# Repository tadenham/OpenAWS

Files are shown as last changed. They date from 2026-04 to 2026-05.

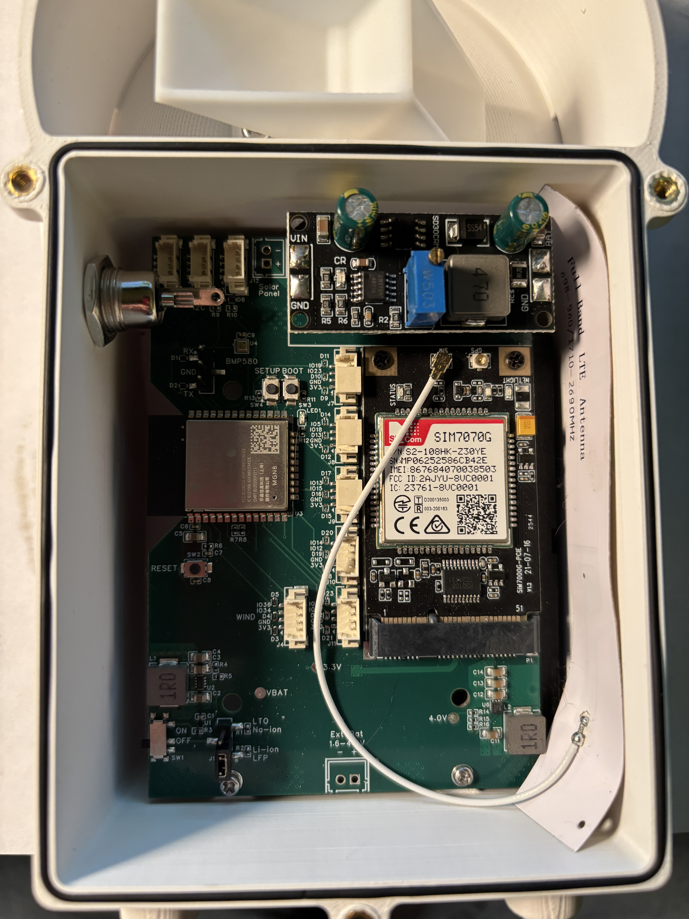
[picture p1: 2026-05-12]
photos/MainPCB.JPG

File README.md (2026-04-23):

OpenAWS is an ESP32-based automated remote weather station. The station transmits via cellular or satellite network.

Currently, the following modules are supported:
 SIMCom SIM7070G (GSM/LTE-M/NB-IoT),
  SIMCom A7670G (GSM/LTE Cat-1),
  and Murata Type 1SC-NTN (NB-NTN geostationary satellite)
 
OpenAWS supports the following sensors:
  temperature/humidity (Sensirion SHT4x or SHT3x),
  precipitation (hall switch),
  barometric pressure (Bosch BMP580),
  wind speed (hall switch),
  and wind direction (AMS AS5600)

The station transmits to the OpenAWS server over UDP and receives a Unix timestamp in response which is used to set the ESP32 clock. This eliminates dependence on unreliable NITZ or NTP updates.
If a response is not received from the server, the data is stored locally and retransmitted at a later time. This ensures guaranteed delivery.

Major station settings are configured in the settings.h file. Otherwise, the station is configured at installation via Bluetooth.

Please visit OpenAWS.org to view stations and further documentation.

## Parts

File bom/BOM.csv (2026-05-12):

Item | Description | Quantity | Material | Notes
1 | Housing, AWS | 1 | ASA | 3D printed
2 | Insert, heat set, M2-0.4 | 3 | Brass | Main PCB/housing
3 | PCB, main | 1 | Various
4 | Holder, battery, 18650, 2-cell | 2 | Various | Soldered to item 3
5 | Battery, lithium-titanate, 18650, 1500 mAh | 4 | Various
6 | Screw, M2-0.4 x 5 mm lg | 3 | Stainless steel | Main PCB/housing
7 | PCB, charger, CN3795 | 1 | Various
8 | Header, male, 2.54 mm pitch, 2P | 2 | Various | Soldered to item 7
9 | Header, female, 2.54 mm pitch, 2P | 2 | Various | Soldered to item 3
10 | Cap, jumper, 2.54 mm pitch, 2P | 1 | Various | Battery voltage selection
11 | PCB, module, SIM7070G | 1 | Various
12 | Standoff, M2-0.4 x 1.5 mm | 2 | Brass | Soldered to item 3
13 | Screw, M2-0.4 x 4 mm | 2 | Stainless steel | Module/Main PCB
14 | Antenna, LTE | 1 | Various | 698-960 MHz, 1710-2690 MHz
15 | Card, SIM, Nano | 1 | Various
16 | Socket, DC, 5.5 mm x 2.1 mm, w/nut | 1 | Various | Solar panel connector
17 | Cable, JST-XH, 2P, 100 mm lg, end 1 female connector, end 2 pigtail, w/male connector | 1 | Various | Solar panel connector
18 | O-ring, 9 mm x 1.2 mm | 1 | Buna-N | Solar panel connector
19 | Plug, snap-in, 8 mm | 1 | Rubber | Use when item 20 is not installed
20 | Receptacle, M8, 4P, rear panel mount, female, w/o-ring and nut | 1 | Various | Required for anemometer
21 | Cable, JST-GH, 4P, 100 mm lg, end 1 female connector, end 2 pigtail | 1 | Various | Required for anemometer
22 | Cable, JST-GH, 4P, 100 mm lg, end 1 female connector, end 2 female connector | 1 | Various | Temperature/humidity sensor
23 | Cover, housing | 1 | ASA | 3D printed
24 | Insert, heat set, M3-0.5 | 4 | Brass | Cover/housing
25 | O-ring, 1.5 mm x 375 mm lg | 1 | Buna-N | Cover/housing
26 | Screw, M3-0.5 x 6 mm | 4 | Stainless steel | Cover/housing
27 | Level, bull's eye, 15 mm x 8 mm | 1 | Various
28 | Insert, heat set, M4-0.7 | 2 | Brass | Radiation shield/housing
29 | Plug, housing | 1 | ASA | 3D printed
30 | Housing, PCB, SHT45 | 1 | 9600 resin | Tap M3-0.5 thru
31 | Insert, PCB, SHT45 | 1 | 9600 resin
32 | Screw, set, nylon-tipped, M3-0.5 x 6 mm | 1 | Various | PCB housing/insert/PCB
33 | PCB, SHT45 | 1 | Various
34 | Plate, shield, radiation, middle | 5 | ASA | 3D printed
35 | Plate, shield, radiation, bottom | 1 | ASA | 3D printed
36 | Screw, socket head, M4-0.7 x 85 mm | 2 | Stainless steel | Radiation shield/housing
37 | Bucket, tipping | 1 | 9600 resin
38 | Pin, dowel, 1/16" x 1-1/4" lg | 1 | Stainless steel | Tipping bucket
39 | Magnet, 1/8" dia. x 1/16" lg, magnetized through thickness | 1 | Neodymium | Tipping bucket
40 | Screen, funnel | 1 | Stainless steel
41 | Mount, panel, solar, adjustable | 1 | ASA | 3D printed
42 | Insert, heat set, M4-0.7 | 2 | Brass | Solar panel mount/housing
43 | Screw, M4-0.7 x 10 mm | 2 | Stainless steel | Solar panel mount/housing
44 | Insert, heat set, M3-0.5 | 2 | Brass | Solar panel/solar panel mount
45 | Panel, solar, 12 V, 4 W | 1 | Various | 2x drill 3mm thru
46 | Screw, M3-0.5 x 6 mm | 2 | Stainless steel | Solar panel/solar panel mount
47 | Washer, flat, M3 | 2 | Stainless steel | Solar panel/solar panel mount
48 | Clamp | 1 | ASA | 3D printed
49 | Insert, heat set, M6-1.0 | 4 | Brass | Clamp/housing
50 | Screw, socket head, M6-1.0 x 35 mm | 4 | Stainless steel | Clamp/housing

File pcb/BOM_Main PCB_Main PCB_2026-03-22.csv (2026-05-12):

No. | Quantity | Comment | Designator | Footprint | Value | Manufacturer Part | Manufacturer | Supplier Part | Supplier
1 | 2 | 2X 18650 | BT1,BT2 | BAT-SMD_BH-18650-B1BA007 |  | BH-18650-B1BA007 | MYOUNG(??) | C6937126 | LCSC
2 | 7 | 100nF | C1,C6,C7,C8,C9,C10,C15 | C0402 | 100nF | CL05B104KO5NNNC | SAMSUNG(??) | C1525 | LCSC
3 | 8 | 22uF | C2,C3,C4,C5,C11,C12,C13,C14 | C0805 | 22uF | CL21A226MAQNNNE | SAMSUNG(??) | C45783 | LCSC
4 | 1 | SMN-303 | CARD1 | SIM-SMD_SMN-303 |  | SMN-303 | XUNPU(??) | C266888 | LCSC
5 | 13 | TPD1E1B04DPYR | D1,D2,D3,D4,D5,D6,D7,D8,D24,D25,D26,D27,D28 | X1SON-2_L1.0-W0.6-P0.65-BI-1 |  | TPD1E1B04DPYR | TI(????) | C779408 | LCSC
6 | 2 | HX PZ2.54-1x3P TP-YQ | J1,J2 | HDR-SMD_3P-P2.54-V-M_HX-PZ2.54-1X3P-TP-YQ |  | HX PZ2.54-1x3P TP-YQ | hanxia(??) | C41417360 | LCSC
7 | 9 | ZX-MX1.25-4PLT | J3,J4,J5,J6,J7,J8,J9,J10,J11 | CONN-SMD_4P-P1.25_MEGASTAR_ZX-MX1.25-4PLT |  | ZX-MX1.25-4PLT | Megastar(??) | C7430475 | LCSC
8 | 1 | ZX-XH2.54-2PZZ | J12 | CONN-TH_2P-P2.50_HX25003-2A |  | ZX-XH2.54-2PZZ | Megastar(??) | C7429632 | LCSC
9 | 2 | PM254V-11-02-H85 | J13,J14 | HDR-TH_2P-P2.54-V-F |  | PM254V-11-02-H85 | XFCN(??) | C541849 | LCSC
10 | 2 | 1uH | L1,L2 | IND-SMD_L7.0-W6.6 | 1uH | FXL0630-1R0-M | cjiang(????) | C167216 | LCSC
11 | 1 | KT-0603R | LED1 | LED0603-RD |  | KT-0603R | KENTO | C2286 | LCSC
12 | 1 | PCIE-52P52H | P1 | CONN-SMD_PCIE-52P52H |  | PCIE-52P52H | XUNPU(??) | C266899 | LCSC
13 | 1 | 200k? | R1 | R0402 | 200k? | 0402WGF2003TCE | UNI-ROYAL(??) | C25764 | LCSC
14 | 1 | 576k? | R2 | R0402 | 576k? | 0402WGF5763TCE | UNI-ROYAL(??) | C27012 | LCSC
15 | 6 | 511k? | R3,R4,R7,R8,R14,R16 | R0402 | 511k? | 0402WGF5113TCE | UNI-ROYAL(??) | C64042 | LCSC
16 | 2 | 91k? | R5,R15 | R0402 | 91k? | 0402WGF9102TCE | UNI-ROYAL(??) | C4147 | LCSC
17 | 2 | 10k? | R6,R13 | R0402 | 10k? | 0402WGF1002TCE | UNI-ROYAL(??) | C25744 | LCSC
18 | 3 | 4.7k? | R9,R10,R11 | R0402 | 4.7k? | 0402WGF4701TCE | UNI-ROYAL(??) | C25900 | LCSC
19 | 1 | 1k? | R12 | R0402 | 1k? | 0402WGF1001TCE | UNI-ROYAL(??) | C11702 | LCSC
20 | 4 | 22? | R17,R18,R19,R20 | R0402 | 22? | 0402WGF220JTCE | UNI-ROYAL(??) | C25092 | LCSC
21 | 1 | SK-3296S-01-L1 | SW1 | SW-SMD_3P-P1.50_L2.7-W6.6 |  | SK-3296S-01-L1 | XKB Connection(????) | C319020 | LCSC
22 | 3 | TS-1088-AR02016 | SW2,SW3,SW4 | SW-SMD_L3.9-W3.0-P4.45 |  | TS-1088-AR02016 | XUNPU(??) | C720477 | LCSC
23 | 3 | Test-Point | TP1,TP2,TP3 | Test-Point-0.5mm
24 | 1 | TLV4041R1YKAR | U1 | DSBGA-4_L0.7-W0.7-R2-C2-P0.35-TL |  | TLV4041R1YKAR | TI(????) | C2871475 | LCSC
25 | 1 | TPS631000DRLR | U2 | SOT-583-8_L2.1-W1.2-P0.50-LS1.6-BL |  | TPS631000DRLR | TI(????) | C5219190 | LCSC
26 | 1 | ESP32-WROOM-32E-N8 | U3 | WIFI-SMD_ESP32-WROOM-32E | 2.4GHz | ESP32-WROOM-32E-N8 | ESPRESSIF(??) | C701342 | LCSC
27 | 1 | BMP580 | U4 | LGA-10_L2.0-W2.0-P0.50-TL_BMP580 |  | BMP580 | Bosch(??) | C22391138 | LCSC
28 | 1 | CC6201ST | U5 | SOT-23-3_L2.9-W1.3-P1.90-LS2.4-BR |  | CC6201ST | CrossChip(????) | C285995 | LCSC
29 | 1 | TPS61022RWUR | U6 | VQFN-7_L2.0-W2.0-P0.55-TL_RWU |  | TPS61022RWUR | TI(????) | C915088 | LCSC

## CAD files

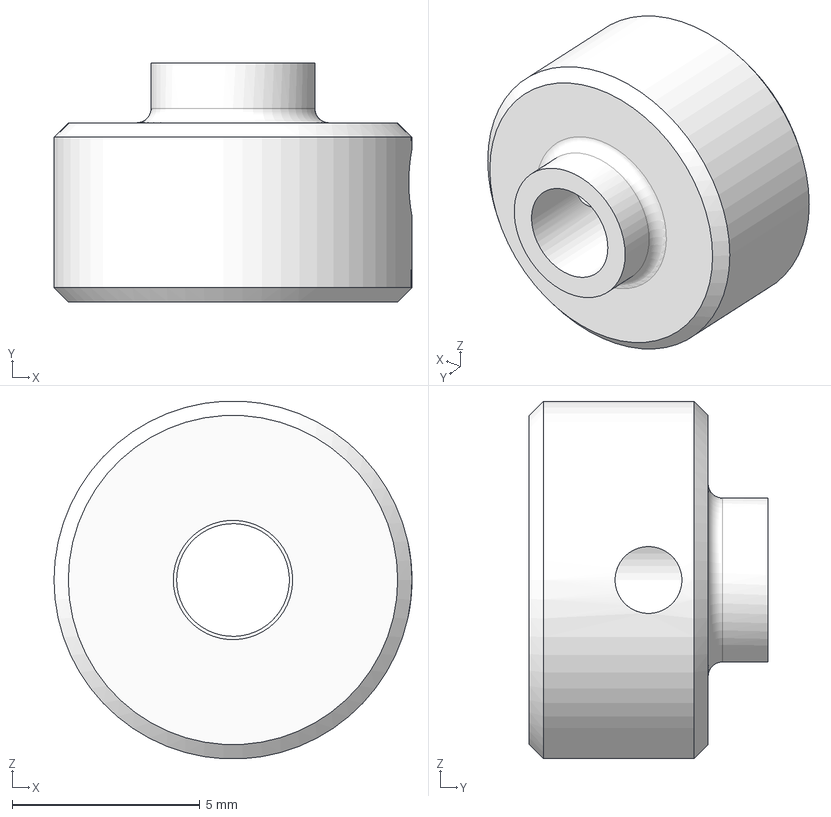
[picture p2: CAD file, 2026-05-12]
cad/WindDirectionMagnetHub.stp
9.52 x 6.35 x 9.51 mm

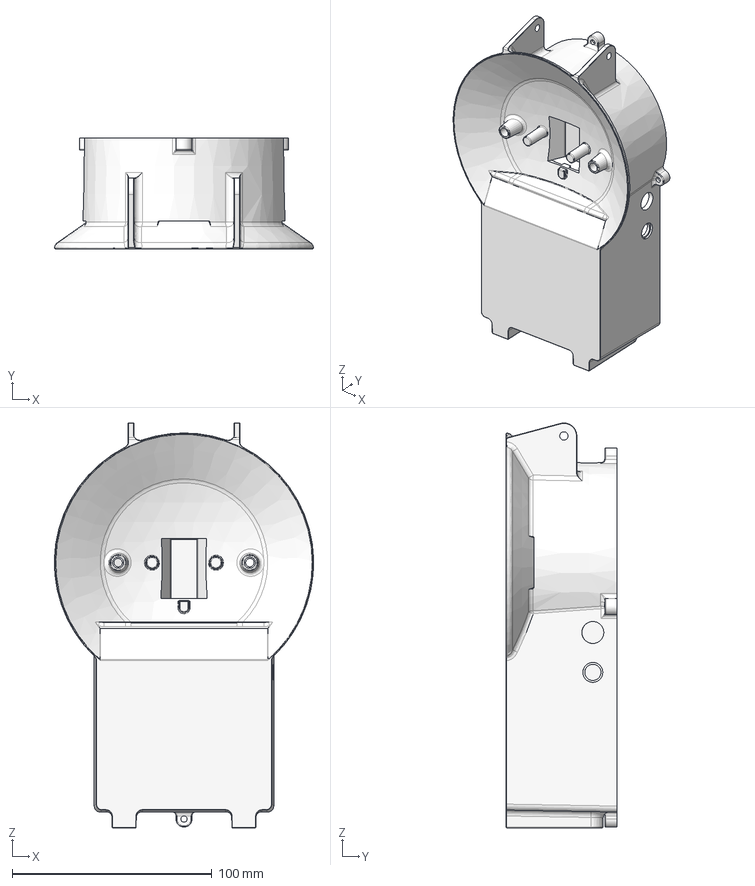
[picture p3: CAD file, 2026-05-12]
cad/AWSHousing.stp
129.9 x 55.4 x 203.0 mm

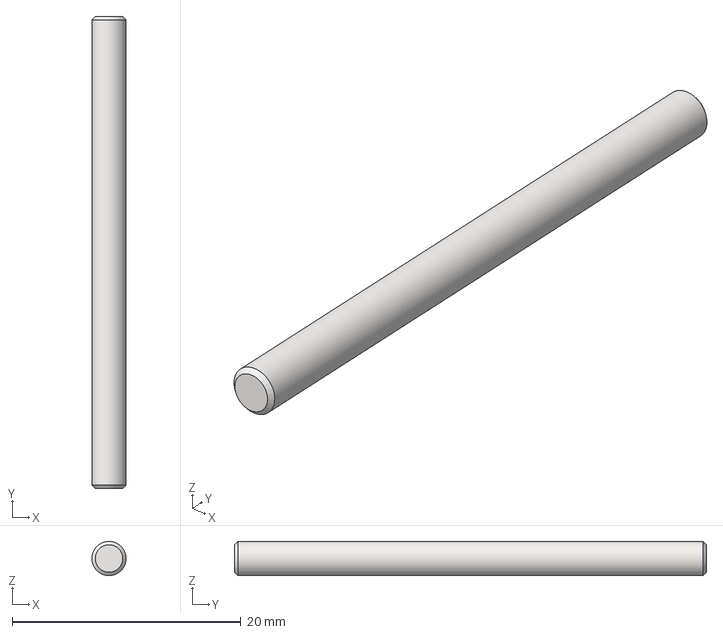
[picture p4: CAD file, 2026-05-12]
cad/WindSpeedShaft.stp
3.00 x 41.3 x 3.00 mm

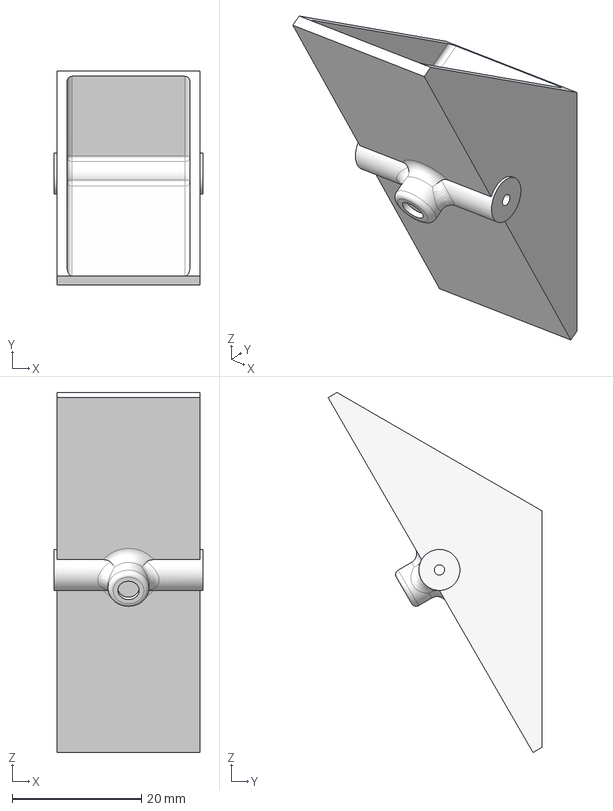
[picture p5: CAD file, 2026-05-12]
cad/RainGaugeBucket.stp
23.0 x 33.1 x 55.8 mm

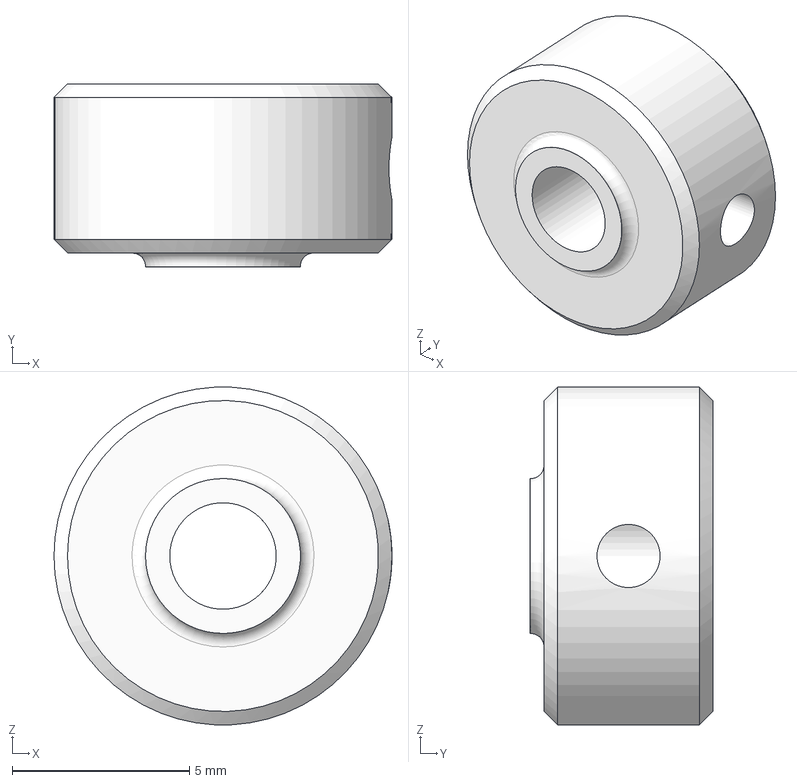
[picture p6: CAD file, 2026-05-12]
cad/ShaftCollar.stp
9.52 x 5.16 x 9.51 mm

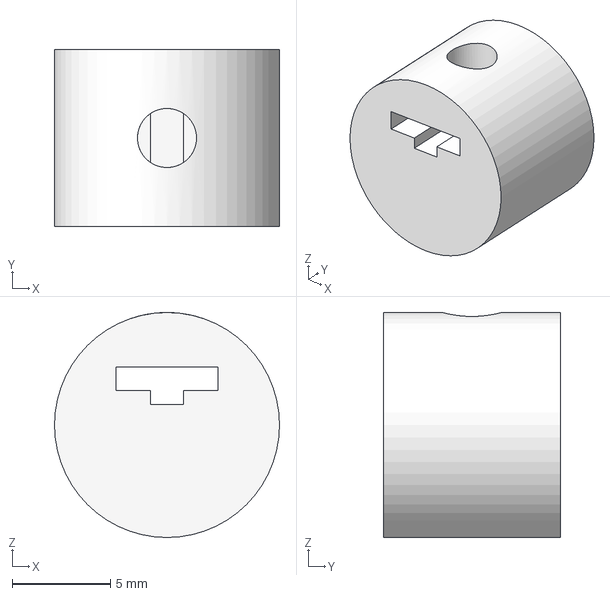
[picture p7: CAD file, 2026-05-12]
cad/TemperatureHumidityPCBInsert.stp
11.4 x 9.00 x 11.4 mm

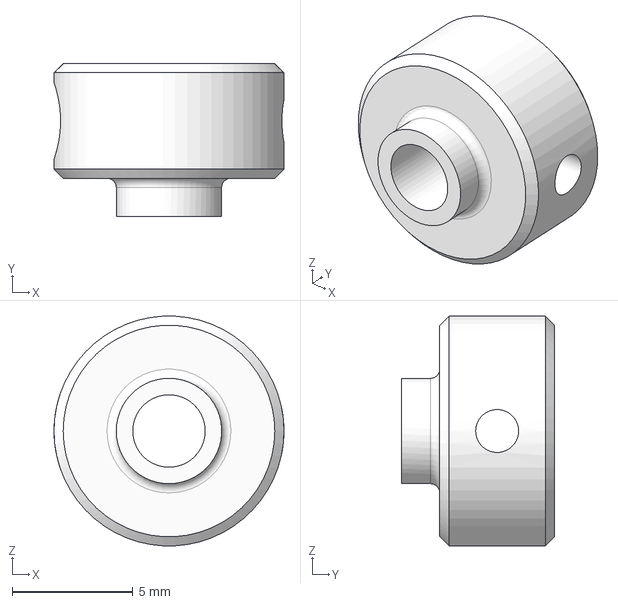
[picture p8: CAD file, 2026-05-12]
cad/WindSpeedMagnetHub.stp
9.52 x 6.35 x 9.51 mm

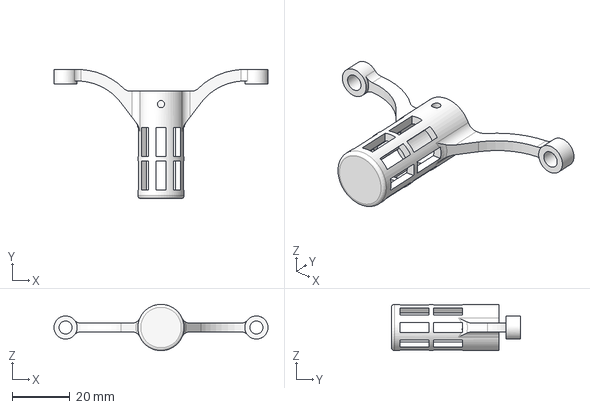
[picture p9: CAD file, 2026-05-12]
cad/TemperatureHumidityPCBHousing.stp
74.0 x 44.7 x 16.0 mm

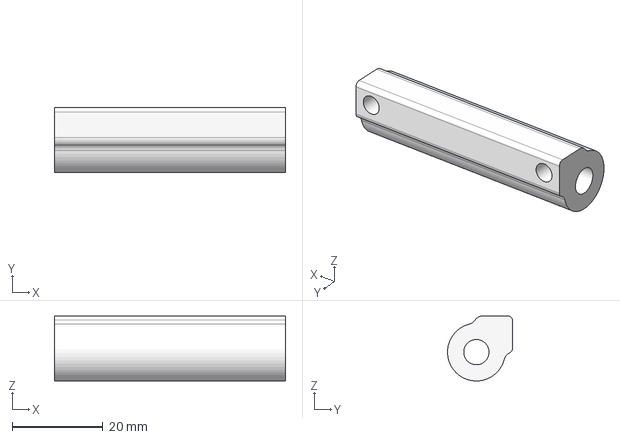
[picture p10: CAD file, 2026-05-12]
cad/SolarPanelMount_Adj.stp
50.8 x 14.3 x 14.3 mm

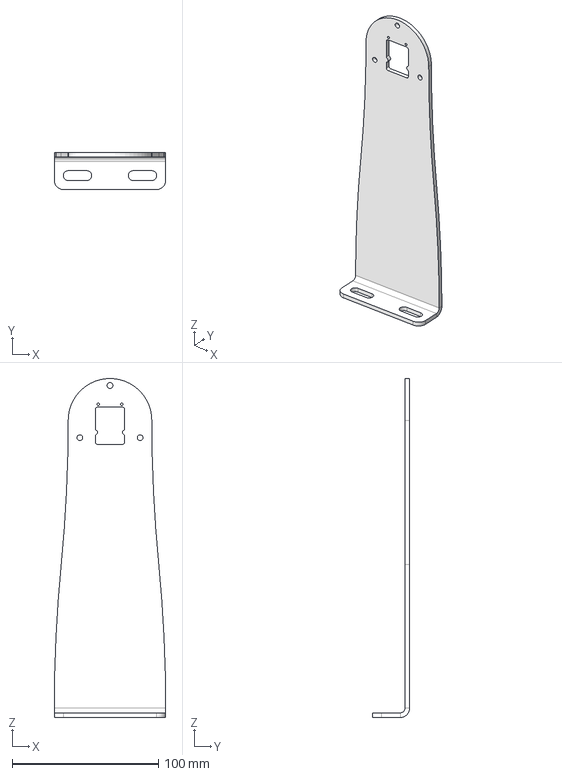
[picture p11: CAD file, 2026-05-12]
cad/AnemometerBracket.stp
76.2 x 25.4 x 231.8 mm

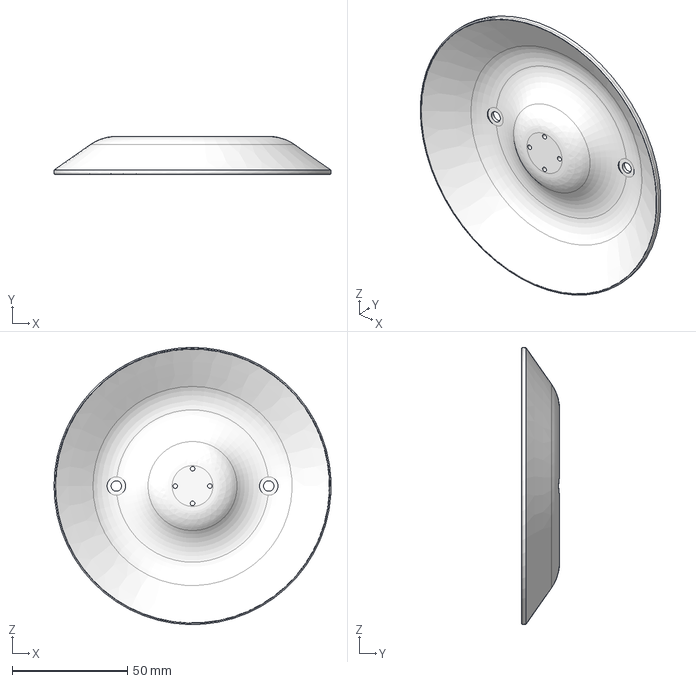
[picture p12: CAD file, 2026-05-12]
cad/RadiationShieldBottomPlate.stp
120.0 x 16.6 x 120.0 mm

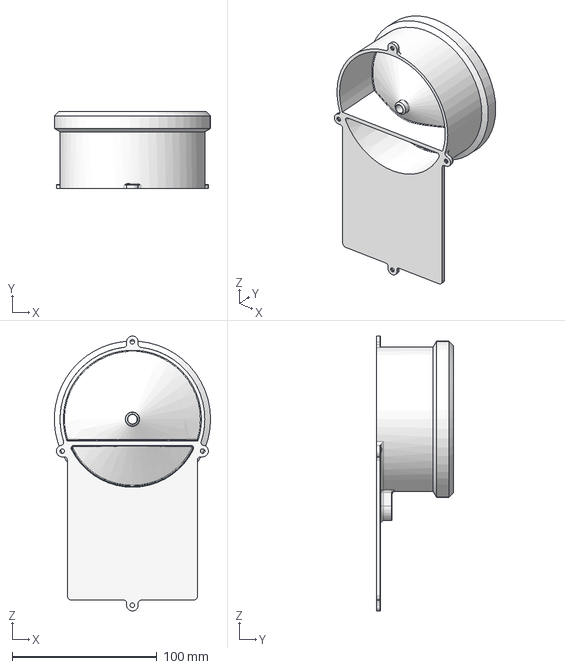
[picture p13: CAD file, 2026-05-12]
cad/AWSHousingCover.stp
107.9 x 53.5 x 190.0 mm

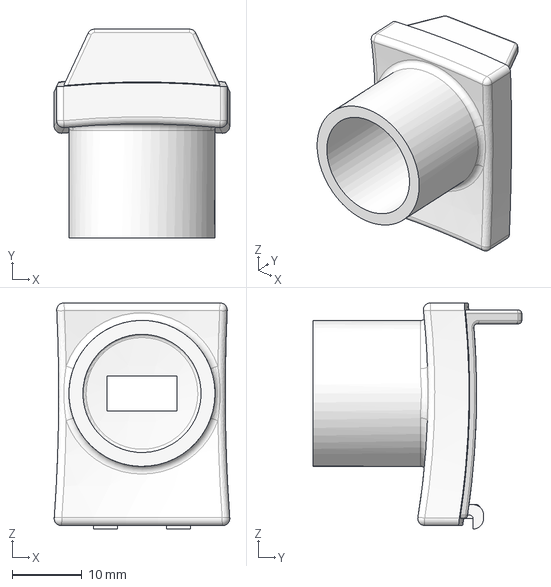
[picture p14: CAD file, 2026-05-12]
cad/AWSHousingPlug.stp
25.3 x 30.0 x 32.5 mm

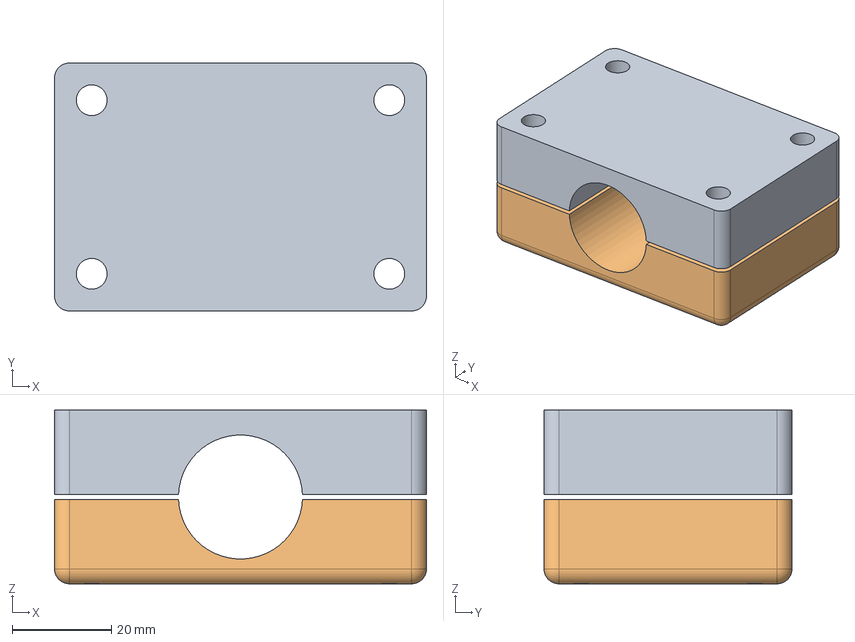
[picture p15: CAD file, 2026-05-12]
cad/Clamp.stp
75.0 x 50.0 x 35.0 mm

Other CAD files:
cad/WindDirectionShaft.stp
cad/WindDirectionHousing.stp
cad/WindSpeedHousing.stp
cad/AnemometerBracket.dxf

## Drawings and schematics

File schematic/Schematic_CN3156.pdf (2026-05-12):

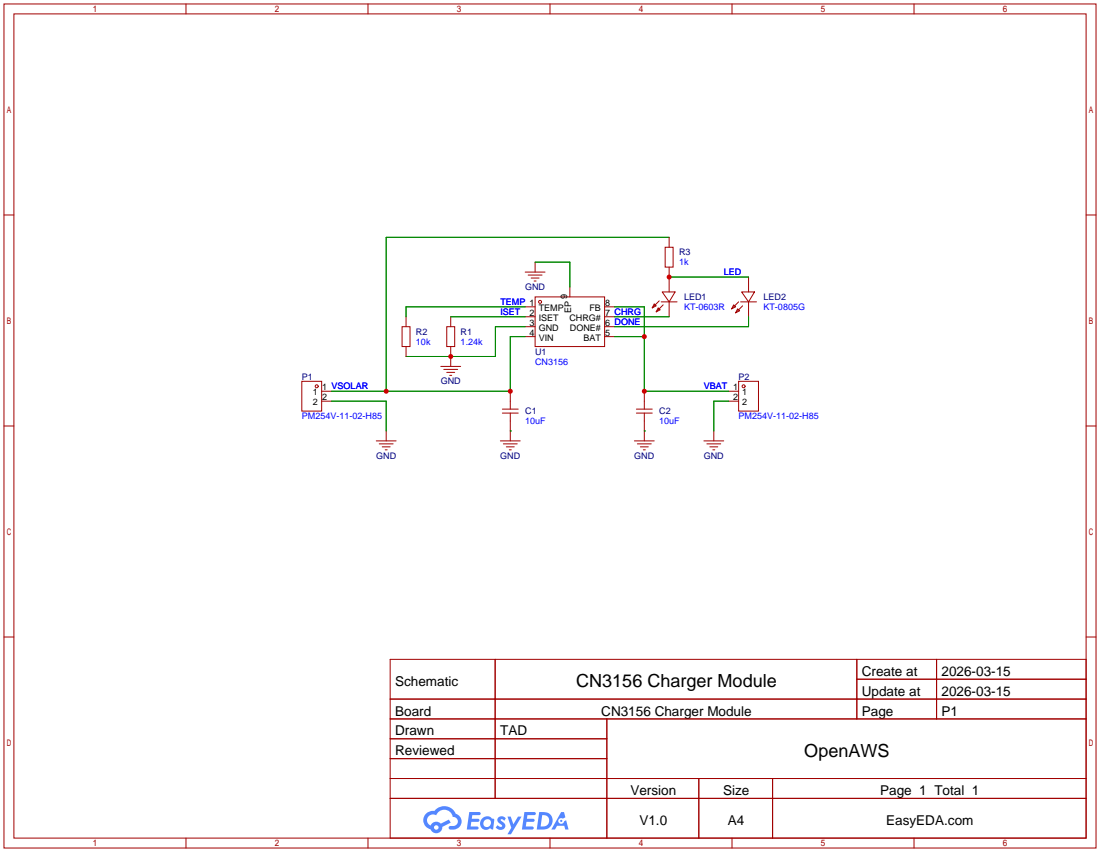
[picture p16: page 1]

Schematic | CN3156 Charger Module | Create at | 2026-03-15

Update at | 2026-03-15

Board | CN3156 Charger Module | Page | P1
Drawn | TAD | OpenAWS
Reviewed

Version | Size | Page 1 Total 1
V1.0 | A4 | EasyEDA.com

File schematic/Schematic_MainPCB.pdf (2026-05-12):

## Battery Connector

# EN_3V3UVLO_COM

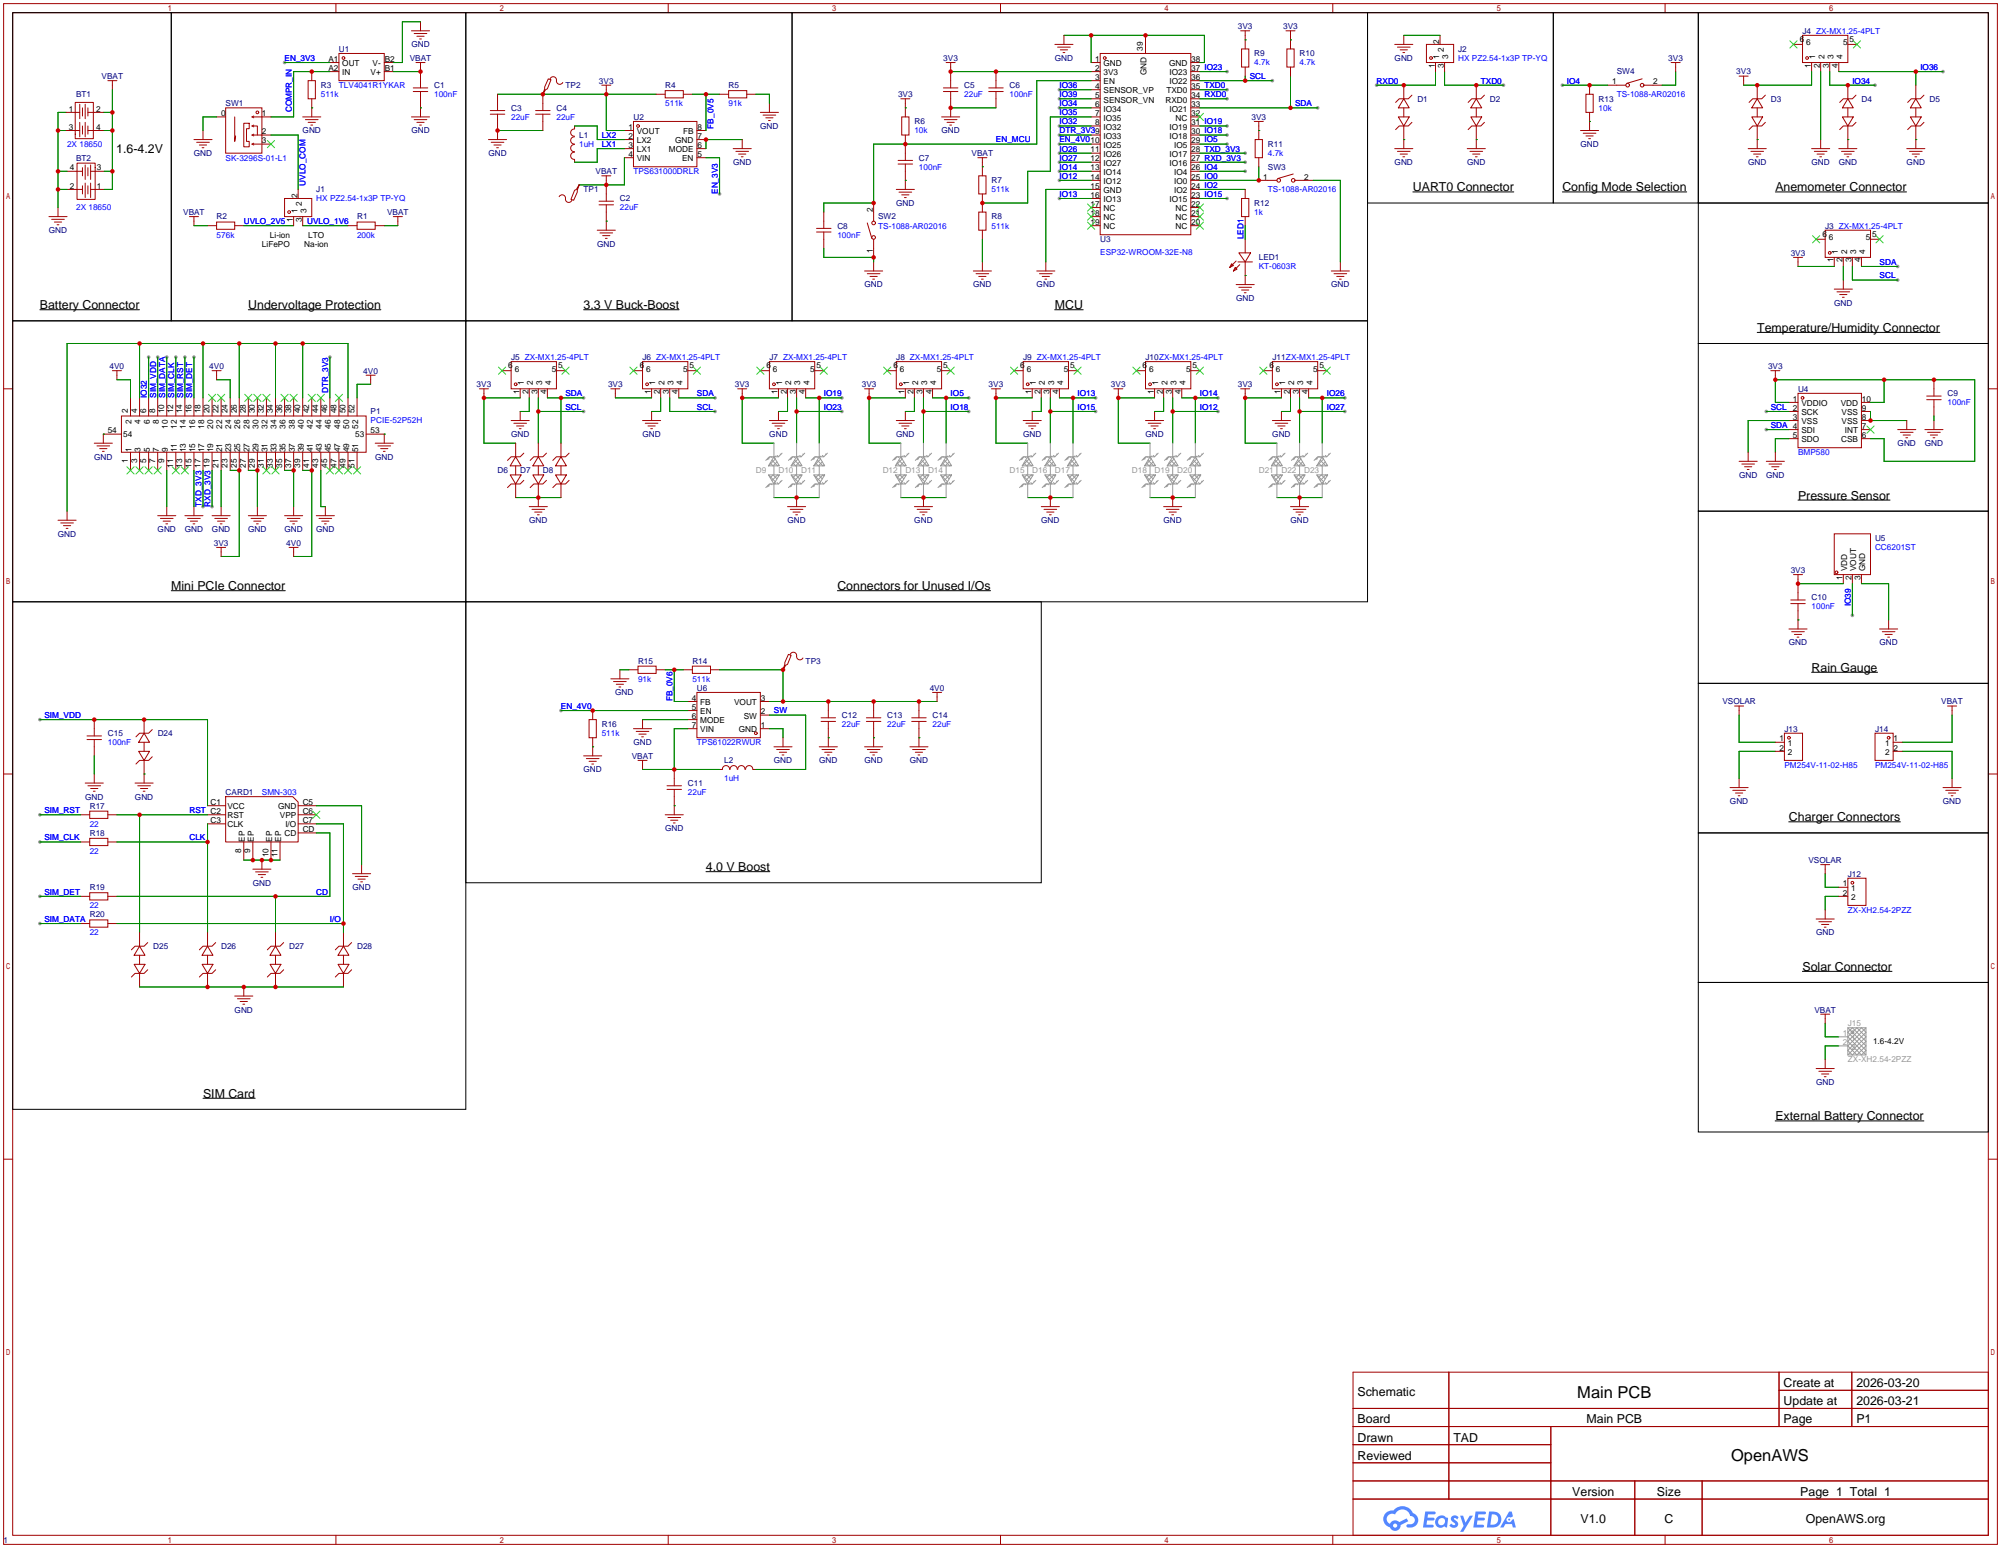
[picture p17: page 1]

Connectors for Unused I/Os

Schematic | Main PCB | Create at | 2026-03-20

Update at | 2026-03-21

Board | Main PCB | Page | P1
Drawn | TAD | OpenAWS
Reviewed

Version | Size | Page 1 Total 1
V1.0 | C | OpenAWS.org

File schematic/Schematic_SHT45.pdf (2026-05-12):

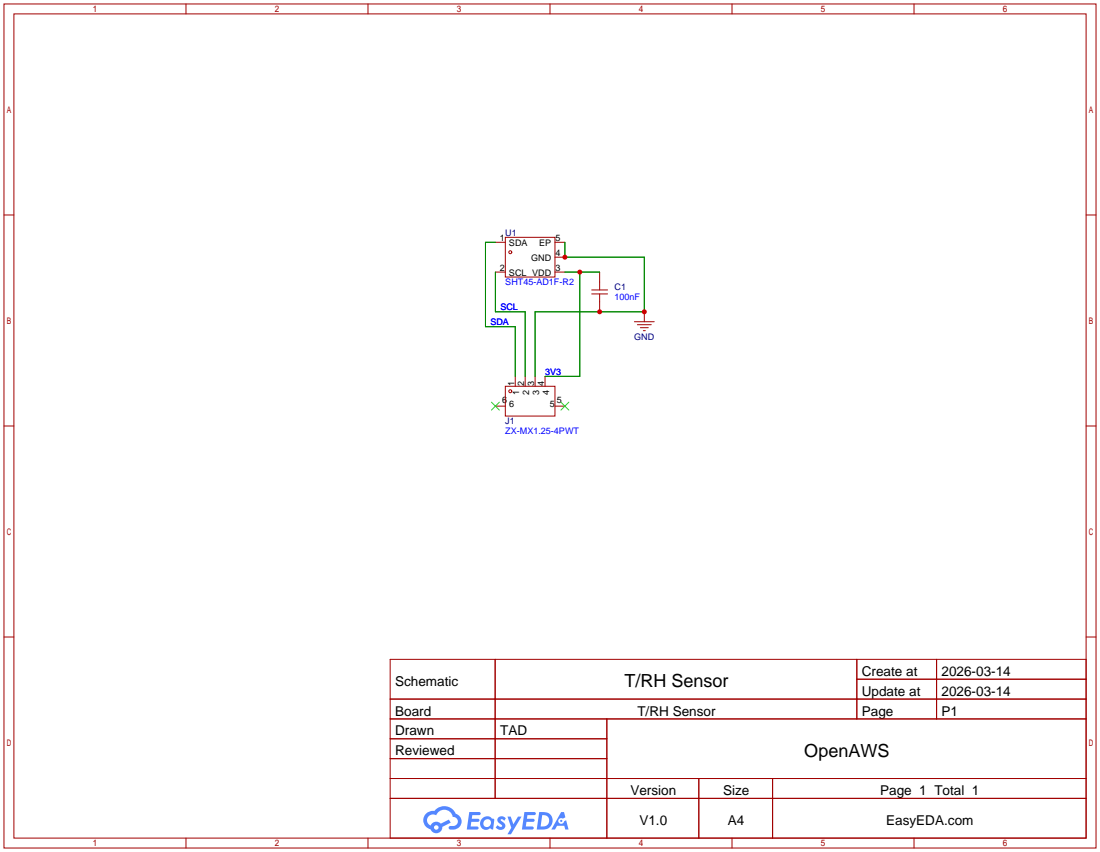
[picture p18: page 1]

Schematic | T/RH Sensor | Create at | 2026-03-14

Update at | 2026-03-14

Board | T/RH Sensor | Page | P1
Drawn | TAD | OpenAWS
Reviewed

Version | Size | Page 1 Total 1
V1.0 | A4 | EasyEDA.com

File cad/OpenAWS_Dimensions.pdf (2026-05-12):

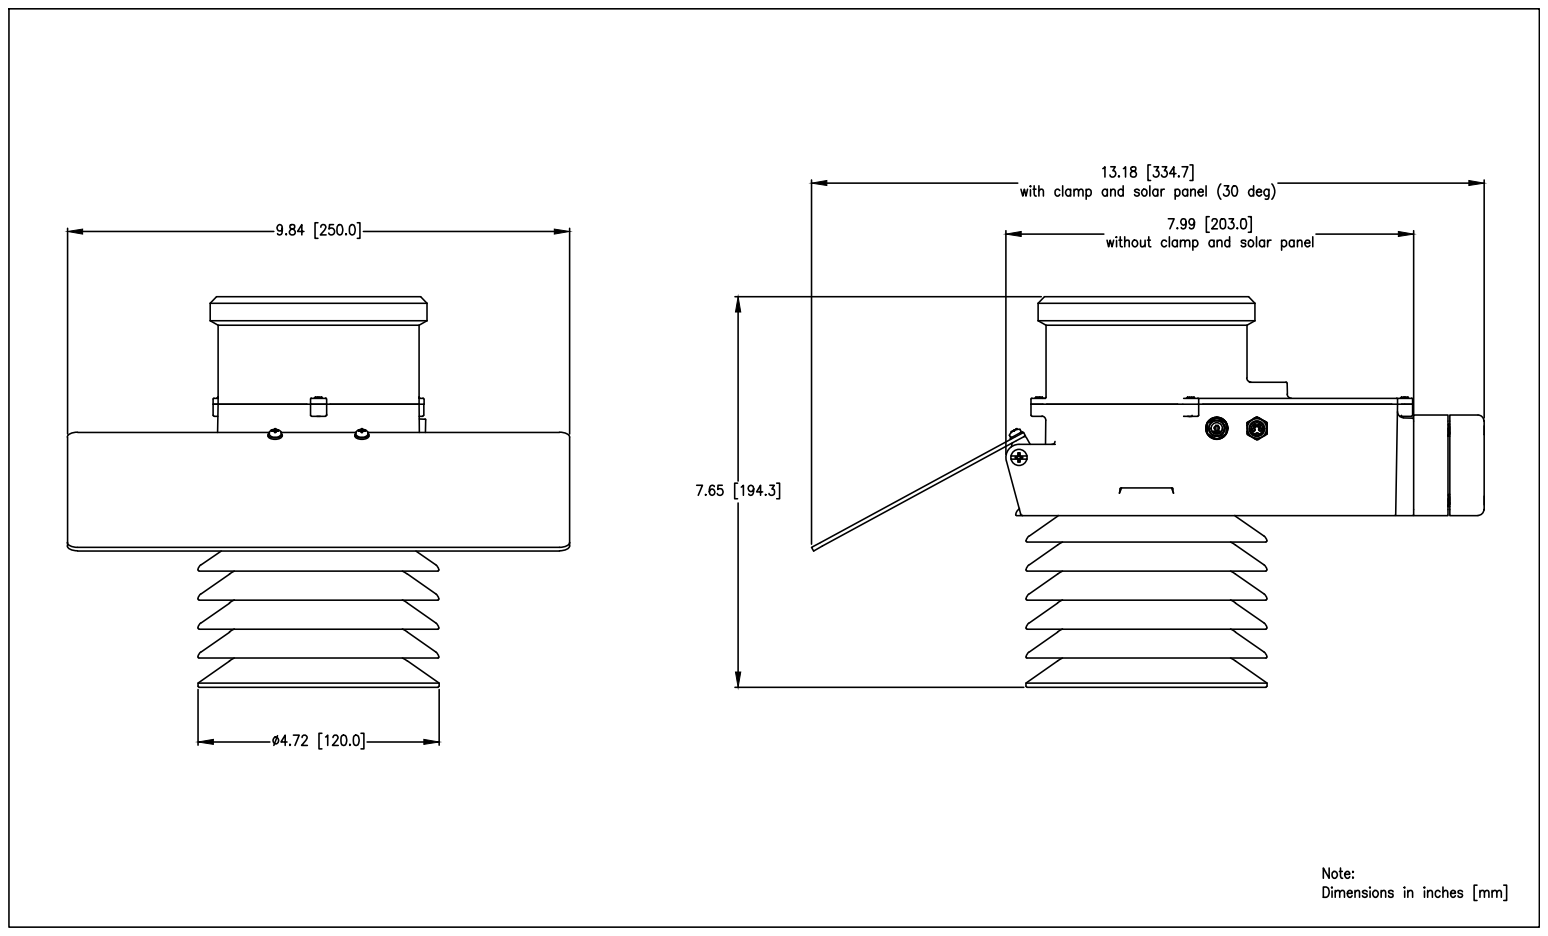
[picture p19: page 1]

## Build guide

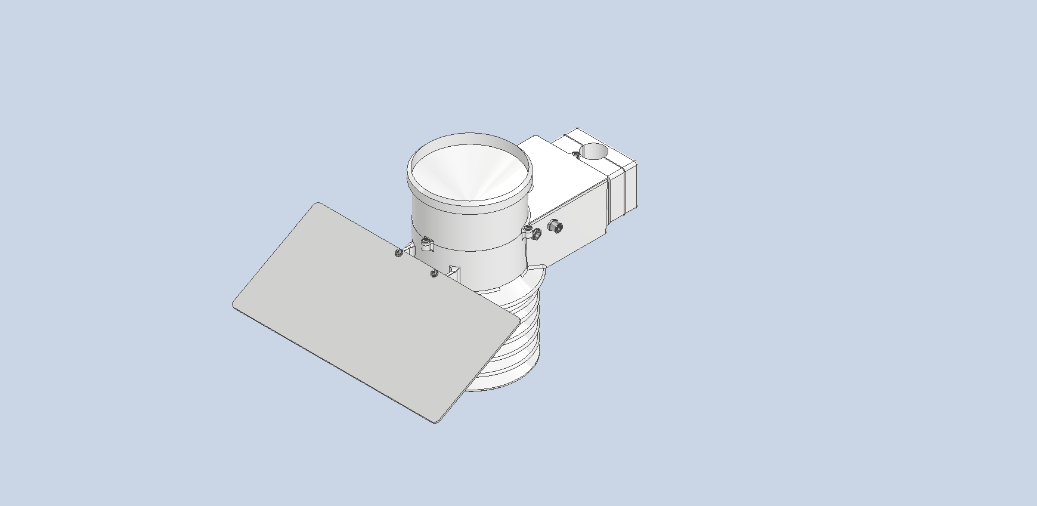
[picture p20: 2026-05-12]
photos/OpenAWSAssembly.png

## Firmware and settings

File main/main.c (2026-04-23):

#include "station.h"
#include "modem.h"

RTC_DATA_ATTR int8_t last_format_min = -1;
RTC_DATA_ATTR int8_t last_format_hour = -1;

EventGroupHandle_t event_group;

RTC_DATA_ATTR bool queued;

RTC_DATA_ATTR struct station station;
RTC_DATA_ATTR struct modem modem;

static struct tm get_time(void)
{
    time_t now;
    time(&now);
    setenv("TZ", station.time_zone, 1);
    tzset();
    struct tm timeinfo;
    localtime_r(&now, &timeinfo);
    return timeinfo;
}

static void create_observation(const struct tm current_time)
{
    ESP_LOGI(TAG, "Creating observation...");
    const uint8_t *data = format_data(current_time, true); // Format observation
    if (current_time.tm_min % station.transmit_interval_min == 0) {
        if (!transmit_data(data)) {
            if (mount_file_system()) {
                write_file(data, "/sdcard/queue.txt");
                unmount_file_system();
                queued = true;
            }
        }
    } else {
        if (mount_file_system()) {
            write_file(data, "/sdcard/queue.txt");
            unmount_file_system();
            queued = true;
        }
    }
    if (current_time.tm_hour == 0) {
        precip = 0;
    }
}

void app_main(void)
{
    station_wake();

    if (station.temp_sensor) {
        xEventGroupWaitBits(event_group, TEMP_BIT, pdTRUE, pdTRUE, 1000 / portTICK_PERIOD_MS); // Wait for at least one temperature/humidity measurement
    }

    if (station.rain_gauge) {
        xEventGroupWaitBits(event_group, PRECIP_BIT, pdTRUE, pdTRUE, 500 / portTICK_PERIOD_MS); // Wait for at least one precipitation measurement
    }

    if (station.anemometer) {
        xEventGroupWaitBits(event_group, WIND_BIT, pdTRUE, pdTRUE, 500 / portTICK_PERIOD_MS); // Wait for at least one wind measurement
    }

    const struct tm current_time = get_time();

    ESP_LOGI(TAG, "The current date/time is: %d-%02d-%02d %02d:%02d:%02d", current_time.tm_year + 1900, current_time.tm_mon + 1, current_time.tm_mday, current_time.tm_hour, current_time.tm_min, current_time.tm_sec);

    if (station.transmit_interval_min < 60) {
        if ((current_time.tm_min % station.observation_interval_min == 0) && current_time.tm_min != last_format_min) {
            last_format_min = current_time.tm_min;
            create_observation(current_time);
        }
    } else {
        if (current_time.tm_min == 0 && current_time.tm_hour != last_format_hour) {
            last_format_hour = current_time.tm_hour;
            create_observation(current_time);
        }
    }
    station_sleep();
}

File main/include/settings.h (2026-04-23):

#ifndef SETTINGS_H
    #define SETTINGS_H

    #define MEASURE_INTERVAL_S_DEFAULT 10
    #define OBSERVATION_INTERVAL_MIN_DEFAULT 5
    #define TRANSMIT_INTERVAL_MIN_DEFAULT 5

    #define TEMP_AVERAGING true
    #define MEASURE_PRESSURE true

    #define RAIN_GAUGE_PIN GPIO_NUM_39
    #define WIND_SPEED_PIN GPIO_NUM_36
    #define WIND_DIRECTION_PIN GPIO_NUM_34
    #define BATTERY_PIN GPIO_NUM_35

    #define SDA_PIN GPIO_NUM_21
    #define SCL_PIN GPIO_NUM_22

    #define CONFIG_PIN GPIO_NUM_4
    #define CONFIG_LED_PIN GPIO_NUM_2

    #define USE_INTERNAL_PULLUPS false

    #define HARDWARE OPENAWS
    //#define HARDWARE ANDGLOBAL
    //#define HARDWARE LILYGO

    #define DEFAULT_APN "iot.1nce.net"

    #define PRESSURE_SENSOR BMP580
    //#define PRESSURE_SENSOR BMP280

    //#define TIME_ZONE_DEFAULT "EST5EDT,M3.2.0,M11.1.0"
    #define TIME_ZONE_DEFAULT "Etc/UTC"

    #define BATTERY_TYPE_DEFAULT LTO
    #define ENABLE_POWER_SAVE true
#endif
